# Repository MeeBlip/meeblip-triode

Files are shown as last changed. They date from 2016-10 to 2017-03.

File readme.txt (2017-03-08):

---------------------------------------------------------------------------------------------------
                     _     _ _         _        _           _      
                    | |   | (_)       | |      (_)         | |     
 _ __ ___   ___  ___| |__ | |_ _ __   | |_ _ __ _  ___   __| | ___ 
| '_ ` _ \ / _ \/ _ \ '_ \| | | '_ \  | __| '__| |/ _ \ / _` |/ _ \
| | | | | |  __/  __/ |_) | | | |_) | | |_| |  | | (_) | (_| |  __/
|_| |_| |_|\___|\___|_.__/|_|_| .__/   \__|_|  |_|\___/ \__,_|\___|
                              | |                                  
                              |_|                                                                                   
---------------------------------------------------------------------------------------------------

Change log
V1.20 2017.02.27 
- MIDI fix so that triode plays nicely with MIDI clock

V1.11 2016.11.23
- Reverted filter decay envelope to use SUSTAIN switch, as in original release 

V1.10 2016.11.12 
- Updated MIDI code to exit interrupt immediately if MIDI command is unrecognized
- Increased front panel switch scanning rate (10X faster)
- Reduced pitchbend to ± 3 semitones
- Altered filter decay envelope to ignore SUSTAIN switch so that filter sweeps continue when key is released
- Removed digital pre-filtering code (previously used on OSC A&B)
- Removed digital enveloping of OSC A & B
- Gate oscillators when amplitude envelope hits zero (prevents audio bleed through)
- Changed filter cutoff curve (use table from MeeBlip SE)
- Scale filter cutoff knob to cover 25%-100% of knob range
- Scale filter resonance knob to cover 25%-100% of knob range
- Added bandlimited square wave tables (pulse waves were previously generated with offset sawtooth ramps)
- Raw calculated waveforms are now used in the lower 4 octaves, then switch to bandlimited wavetables. 
-Flipped waveforms to match phase and avoid a pop when crossing the cut-over point
 
V1.01 2016.10.24 
- Ensure MIDI channel settings are saved correctly when powered off for Channel 1-8 (implement MAXMIDI variable)
- Allow MIDI CC control of GLIDE knob to select waves when in wavetable mode (CC 61 now controls GLIDE in wavetable mode)
- Updated MIDI code to exit interrupt immediately if MIDI command is unrecognized
- Increased front panel switch scanning rate (10X faster)

V1.00 2016.10.19 
- Initial release

---------------------------------------------------------------------------------------------------

  MeeBlip hardware is released under a Creative Commons Attribution-ShareAlike 4.0 International 
	(CC-BY-SA 4.0) license. You are free to share and transform this work, even for commercial
	purposes, providing you:

	1. Give appropriate credit, provide a link to the license, and indicate if changes were made. 
	   You can say something such as "This project is based upon the MeeBlip anode synthesizer. 
	   For more information, visit meeblip.com or download source code and design files at 
	   https://github.com/MeeBlip"

	2. If you remix, transform, or build upon the material, you must distribute your contributions
	   under the same license as the original. That means making source code, design files and PC 
	   board layout files available so someone can build and modify their own version of the project. 

	3. The MeeBlip name is our intellectual property. You are not allowed to release commercial 
	   devices based on our designs using the MeeBlip brand name. 
	
	Here's are links to the Creative Commons license, for the design:
	http://creativecommons.org/licenses/by-sa/4.0/
	http://creativecommons.org/licenses/by-sa/4.0/legalcode

	MeeBlip source code and documentation is released under a GPLv3 license. 

  A copy is available in the MeeBlip repository at:
	https://github.com/MeeBlip/meeblip-anode/blob/master/LICENSE

	MeeBlip Contributors

	Jarek Ziembicki	- Created the original AVRsynth, upon which this project is based.
	Laurie Biddulph	- Worked with Jarek to translate his comments into English, ported to Atmega16
	Daniel Kruszyna	- Extended AVRsynth (several of his ideas are incorporated in MeeBlip)
 	Julian Schmidt	- Original Meeblip digital filter algorithm
	Axel Werner		- Code optimization, bug fixes and new bandlimited waveforms 
	James Grahame 	- Meeblip hardware and firmware development

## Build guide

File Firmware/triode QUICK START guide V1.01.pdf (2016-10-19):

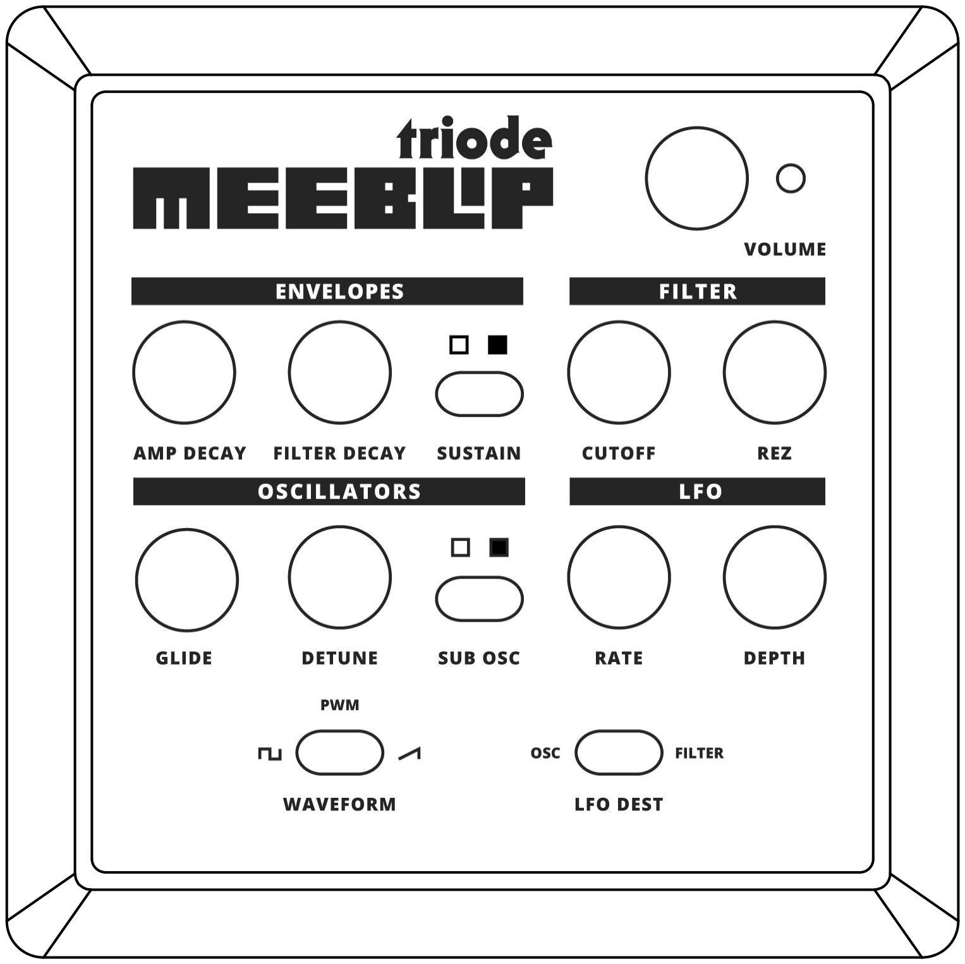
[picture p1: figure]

# QUICK START INSTRUCTIONS

### Firmware Version 1.0

Thanks for buying a MeeBlip, and welcome to triode! Let’s get started.

# Connect triode

triode requires three connections: MIDI, 9V DC power and Audio.

For audio, connect any stereo mini jack (3.5 mm) cable to an external output, or plug in stereo headphones. IMPORTANT: you must use a stereo cable connected to a stereo input jack.

MIDI input is available from any standard MIDI DIN connection. (That’s the round connector with the five pins.)

Power is 9V DC, 300 mA, 2.1mm-barrel, center positive.

# Set the MIDI Channel

Set the MIDI channel using the MIDI SET button on the back panel. Press it until the LED blinks, then release. Move one of the control knobs corresponding to channels 1 to 8. The LED will blink quickly to confirm that the MIDI channel has been changed.

# Turn it on

Flip the power switch on the back panel right to turn triode on. The power LED blinks when receiving MIDI notes.

# Adjust the controls

triode’s controls are divided into sections that control the sound of each note over time (envelope), shape its timbre (filter), control its sound source (oscillators), and add modulation (LFO).

AMPLITUDE & FILTER ENVELOPES: With SUSTAIN switched to off, triode uses single stage decay envelopes for amplitude and filter cutoff. With SUSTAIN on, they becomes two-stage envelopes (Sustain/Decay) where DECAY controls both sustain and release times. ATTACK can be adjusted for both envelopes using MIDI CC.

OSCILLATORS: triode is a three-oscillator synth. Two oscillators can be switched between Pulse, Pulse with PWM, and Sawtooth waveforms. The third is a square wave sub-oscillator which plays an octave lower.

GLIDE adjusts the speed with which notes slide from one to another. Turn the knob fully to the left to disable.

DETUNE adjusts the pitch of the second oscillator up or down an augmented fifth (eight semitones). The oscillators can be precisely tuned to each other at the 12 O’clock position of the knob.

SUB OSC activates the square wave sub-oscillator, which plays an octave lower than the primary oscillators.

LFO RATE determines the speed of the Low Frequency Oscillator (LFO). Disable by turning the knob fully to the left.

LFO DEPTH is the modulation amount of the LFO. Disable by turning knob fully to the left.

LFO DEST sets the LFO to modulate either the pitch of the two oscillators or the cutoff of the analog filter.

FILTER: triode has a unique-sounding low pass Twin-T filter, with controls for CUTOFF and REZ (resonance). Turn REZ all the way up for squelchy self-resonation. Try turning CUTOFF up and REZ down when experimenting with other values.

# Play some notes

triode responds to notes, pitch bend, mod wheel, velocity (mapped to filter cutoff), and CC messages (see table).

# How triode responds to MIDI

In addition to pitch (MIDI notes) and velocity (mapped to the filter envelope, so triode responds to how forcibly you play notes), triode responds to MIDI messages from external controllers and sequencers. MIDI numbers these messages via standard Control Change numbers, or CC:

### 01 MIDI MOD wheel (mapped to LFO Depth)

Knobs

### 48 LFO Depth 49 LFO Rate 50 Oscillator Detune 51 Note Glide (Portamento) 52 Filter Resonance 53 Filter Cutoff 54 Filter Decay 55 Amplitude Decay

Knobs only accessible via MIDI:

### 56 Filter Accent 57 Filter Envelope Modulation 58 Oscillator Pulse Width 59 Filter Attack 60 Amplitude Attack

Switches

### 64 Envelope Sustain 65 Sub-oscillator 66 PWM Sweep 67 LFO Destination (osc/filter) 68 Oscillator Wave (pulse/sawtooth)

Since switches are either in one position or another, any CC with a value from 0-63 will correspond to “off”; any value from 64-127 will result in “on.”

Switches only accessible via MIDI:

### 69 LFO Randomize 70 LFO Note Retrigger (default ON)

# To activate Wavetable Mode

Hold the MIDI Set button for a moment while turning the instrument on. The LED will flash quickly to indicate that it has switched firmware. The WAVEFORM switch selects Wavetable Bank A / B / C and the GLIDE knob selects one of the 8 waveforms in each bank.

Wave Bank A: Sawtooth, Blended Sawtooth, FM 1, Distorted 1, Granular 1, Voice 1, Voice 2

Wave Bank B: Bit Reduced 1, Bit Reduced 2, Bit Reduced 3, Distorted 2, Distorted 3, FM 2, FM 3, More Granular.

Wave Bank C: Chip Osc 1, Chip Osc 2, Video Game 1, Video Game 2, Bit Reduced 4, Bit Reduced 5, Raw 1, Raw 2

# What’s next?

Have fun! You can find advanced documentation including schematic diagrams and source code, at our site: meeblip.com. You can also email us at meeblip@reflexaudio.com

Assembled in Canada by Blipsonic Inc. MeeBlip is a project of Blipsonic and CDM (cdm.link)

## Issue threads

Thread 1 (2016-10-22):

The Triode should better filter unknown MIDI messages

samboy, 2016-10-22:
There is an issue reported by [a user on Reddit](https://www.reddit.com/r/synthesizers/comments/58phrq/filtering_out_midi_clock/) that the Meeblip Triode has issues receiving MIDI note on messages when receiving a number of presumably unknown MIDI messages, probably either MIDI [Song Position Pointer](http://www.recordingblogs.com/sa/Wiki/topic/MIDI-Song-Position-Pointer-message) or [MTC](https://en.wikipedia.org/wiki/MIDI_timecode) message.

Looking at [mini_in.inc](https://github.com/MeeBlip/meeblip-triode/blob/master/Firmware/midi_in.inc), as of commit c66a3ed, there is code between lines 23 and 29 which immediately removes the Triode from the interrupt caused by a MIDI message sent should it be a byte between F0 and FF. And, indeed, when my Triode gets a [MIDI Beat Clock](https://en.wikipedia.org/wiki/MIDI_beat_clock) message from my Korg ER-1 along with note-on commands, the Triode is able to play the notes without problem, since MIDI Beat Clock only consists of the bytes F8, FA, FB, and FC.

However, the Triode stops being able to respond to MIDI messages when getting more complicated unknown MIDI messages. Looking at mini_in.inc, the issue appears to be that, when MIDIPHASE (the byte of a MIDI message we are looking at) is 0, and an unknown byte is received, instead of immediately exiting from the MIDI interrupt, mini_in.inc compares the incoming byte and MIDIPHASE to a number of possible values before finally exiting the interrupt.

To resolve this, I propose adding two instructions right after the INTRX_DATA jump point, on line 73 of the current version of midi_in.inc, like this:

```
INTRX_DATA:
 lds r17, MIDIPHASE ; This is already here on line 73
 cpi r17, 0 ; On the old 6502, this isn't needed
 breq INTRX_ACPT_X ; Which will jump us to INTRX_EXIT
 cpi r17, 0x80 ; This is in the current code; go on as the current code does
```

Thoughts? This fix should make the Triode more useful when slaved to devices which send complex MIDI data when sending out a clock signal over MIDI.

Edit: Looking at the code again, INTRX_ACPT_X is close enough to this that we can call that with [BREQ](http://www.atmel.com/webdoc/avrassembler/avrassembler.wb_BREQ.html)

jgrahame, 2016-10-23:
Will implement and test.

jgrahame, 2016-10-25:
Hi Sam -

Thanks for the message. Will have to do a careful walkthrough to be sure,
but this might sort the issue out. Will try it later this weekend and let
you know how things go.

Cheers, James

On Fri, Oct 21, 2016 at 10:46 PM, Sam Trenholme <notifications@github.com>
wrote:

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

jgrahame, 2016-10-26:
Implemented change. Tested extensively and couldn't get it to fail. Online comments suggest Elektron is doing something unusual with the Octatrack MIDI clock output. Will investigate with their hardware.

jgrahame, 2016-10-29:
Hey sam -

After feedback from users...

We'll be releasing V1.1 of the firmware next week, which has MIDI
improvements, better filter behaviour (especially low), better
enveloping and some voicing improvements as well. It's a significant
upgrade that makes a big difference to the instrument's sound.

The upgrade will be available as a replacement chip or download for
people who own AVR programmers. More details soon!

James Grahame

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

samboy, 2016-11-01:
How much will a replacement ATmega chip for the Triode cost, and how can one go about ordering one?

— Sam (I prefer the chip solution, because, over the long term, it’s more sustainable)

Closed 2016-10-26.

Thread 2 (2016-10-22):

Midi channels above 4 are not restored

oO, 2016-10-22:
When I set the midi channel to 8, the triode reverts to channel 0 / omni mode on power up.

The initialize code checks for midi channel < 5 but we can now pick values from 1-8 as valid midi channels?

initialize.inc line 223
````asm
cpi		r16, 5
brlo	LOAD_MIDI_CHANNEL		; If stored MIDI Channel is not Channel 1-4, set synth into MIDI OMNI mode.
ldi		r16, 0
````

Seems that you should check for values less than 16 instead, and worry about how many channel the synth supports somewhere else.

In the future, you could check for a change in the state of a switch to toggle between midi 1-8 and 9-16 and support setting the synth to any channel. and not just the lower 8 channels.

jgrahame, 2016-10-23:
This should be an easy fix. Will implement in the next release.

jgrahame, 2016-10-26:
Added MAXMIDI variable. Synth now restores channel 1-8 after being powered down.

oO-Zam, 2016-10-31:
@jgrahame what's the process to update the firmware? I'm assuming the .hex file is updated to 1.01, so I can just fire up AVRDUDE and flash it? ( don't think you have the onboard programming pins exposed on the synth, right? )

Closed 2016-10-26.

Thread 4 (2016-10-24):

Midi CC for Sub-Oscillator level (volume)

oO, 2016-10-24:
Looking at the code, (not an Assembly programmer, so it reads, very very slowly) it seems possible to support control of the sub-oscillator level from Midi CC (I guess a mult rather than a if somewhere?) . I would change the way the CC#64 works by using the full range 0-127 for volume, instead of on/off at >=64. You can still have full bypass of the sub calculation at level = 0

Also is the sub-oscillator 1 or 2 octaves down? This is orthogonal from the Midi CC question, but since your switches have 2 states, you could actually have the sub function as Off/-1/-2

jgrahame, 2016-10-26:
The sub-osc output is mixed with the main oscillators as an analog signal. There is no control of amplitude.

Closed 2016-10-26.

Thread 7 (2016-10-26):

Publish a BOM

oO, 2016-10-26:
Since the MeeBlip is Open Hardware / Open Source, would you mind adding a Bill Of Materials to the repository? Also I'm guessing you don't have a bootstrap and program the ATMEGA chip directly?

I might play with an alternate build at some point, but I'll probably do it on a separate chip, and keep yours for the "official" build.

Great little bass synth BTW, it sounds really dirty but that's not a bad thing.

lukeoftheaura, 2017-06-04:
+1 for adding a BOM.

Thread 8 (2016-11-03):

panic button for hung notes

oO-Zam, 2016-11-03:
I'm getting a lot of stuck notes and missed midi events from my MeeBlip when driving it from the Squarp Pyramid. It would be great to have the midi button stop all open notes when pressed ( or whatever scheme would allow me to have a quick "panic button" to use.

Alternativelly, supporting the "AllNotesOff" midi message would also be great.

jgrahame, 2016-11-03:
We'll be releasing a firmware update later this week that uses significantly fewer processor cycles, would be great if you could test that with the Pyramid.

oO-Zam, 2016-11-03:
Will do. Still think turning the button into a panic button would be great. You can double up with the Midi setting, since you probably want to stop all notes when switching channels.

jgrahame, 2017-04-12:
Version 1.20 fixes issues with MIDI clock and hung notes.

Closed 2017-04-12.

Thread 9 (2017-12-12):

3-way switch via midi isn't working

evanmcc, 2017-12-12:
Hi, I have a triode and have only recently been playing with wavetable mode.  I've also gotten a new sequencer recently and in programming in the various CCs for the meeblip, I noticed that the three-way switch only does positions one and three via MIDI, right at value 64, as you'd expect from a two-way switch.  The hardware works fine.  I think that I confirmed that you can't get PWM via MIDI either.

Also a feature request, albeit one that might not be possible: I'd love to be able to trigger wavetable mode via CC as well, as it'd go a long way towards being able to replicate patch memory in the sequencer.

Lastly a hardware question: is modding the triode to be actually mono as simple as snipping the ring legs on the socket, or will that not work?

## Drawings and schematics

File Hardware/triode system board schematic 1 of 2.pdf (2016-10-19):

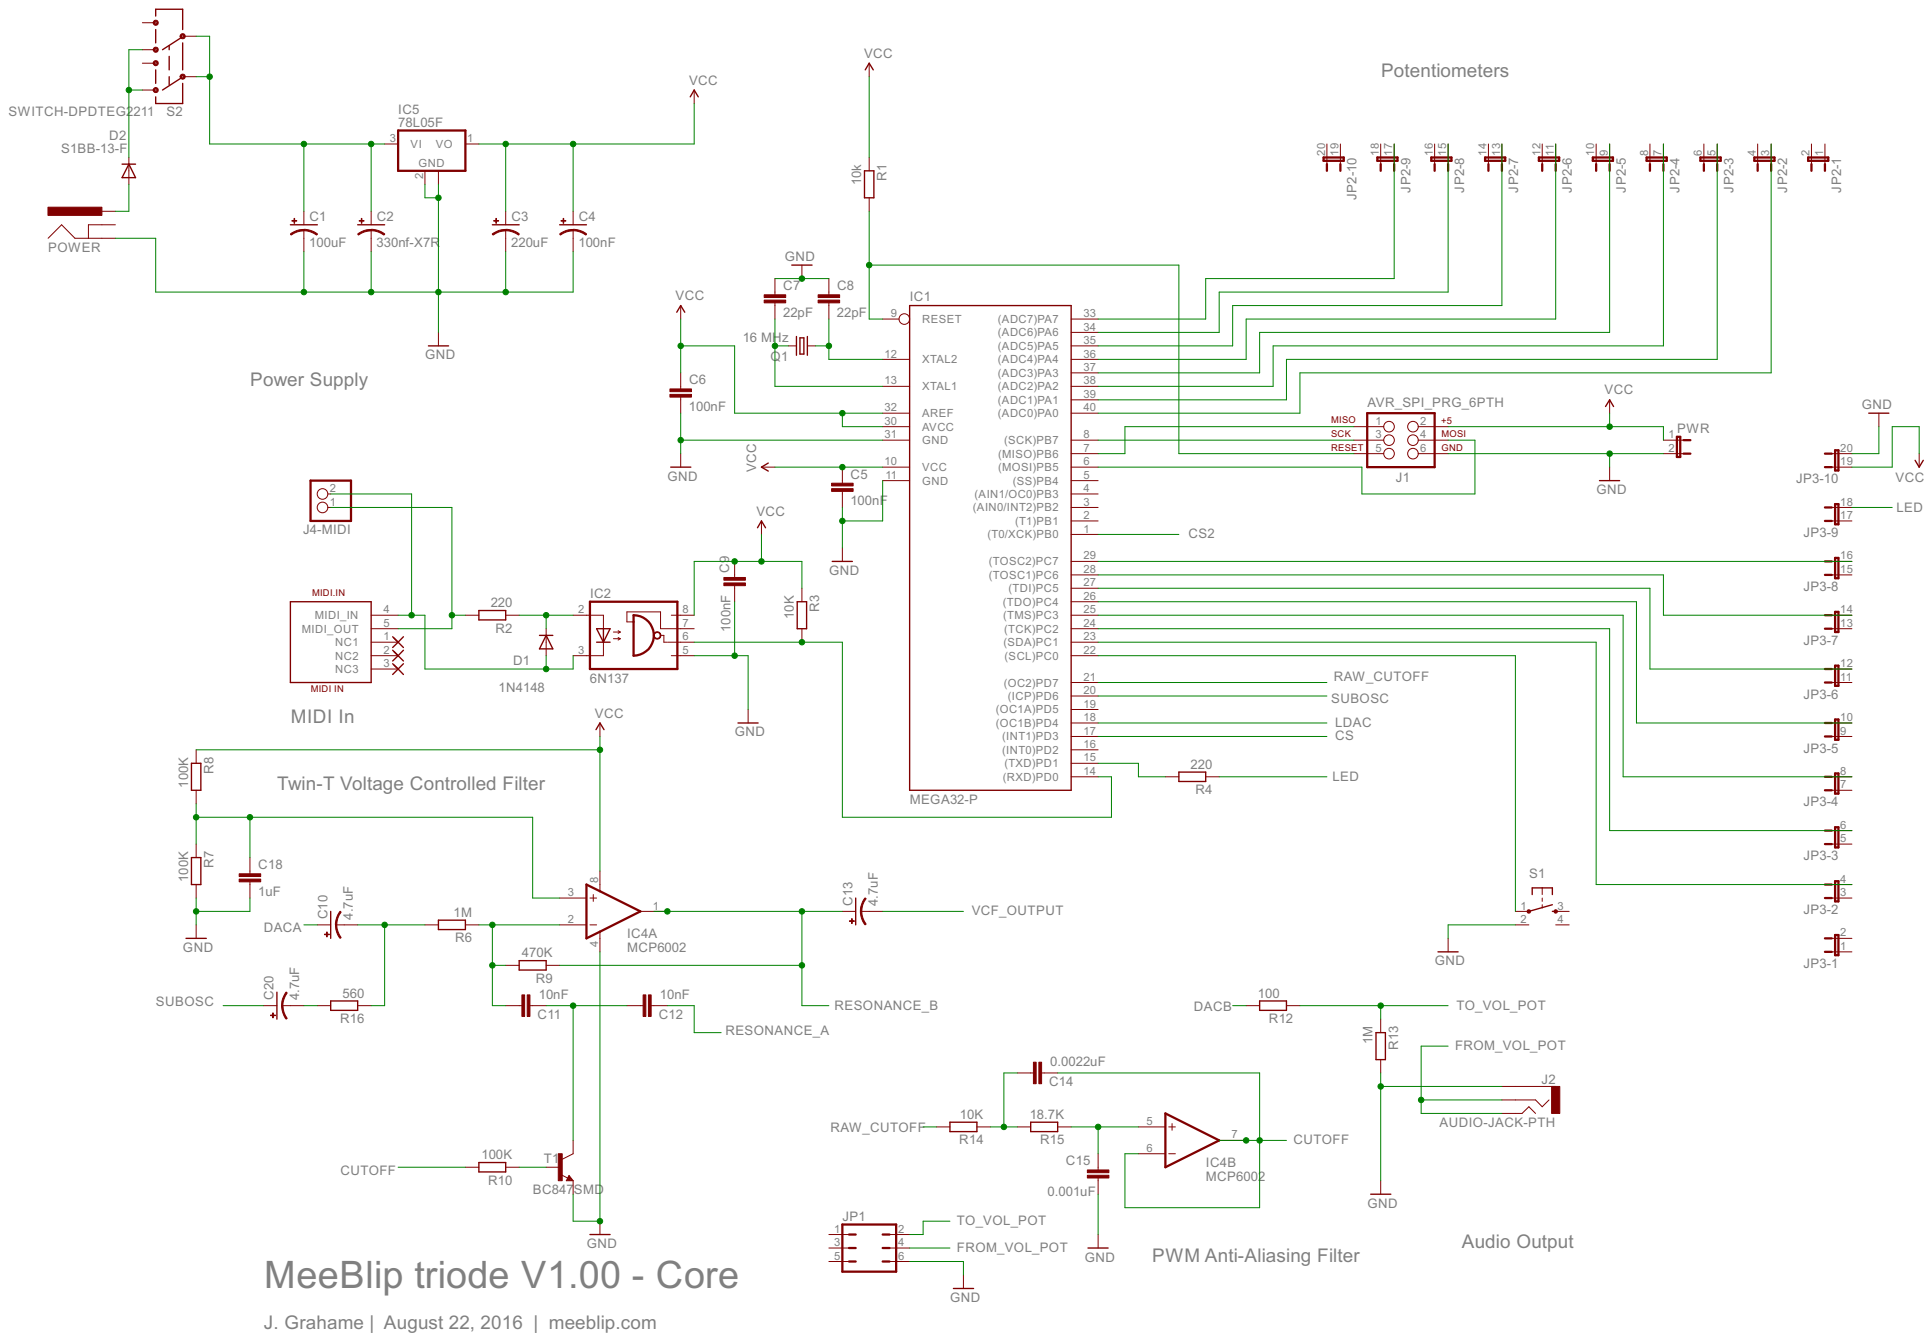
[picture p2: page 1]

MIDI.IN MIDI IN

Twin-T Voltage Controlled Filter

J. Grahame | August 22, 2016 | meeblip.com

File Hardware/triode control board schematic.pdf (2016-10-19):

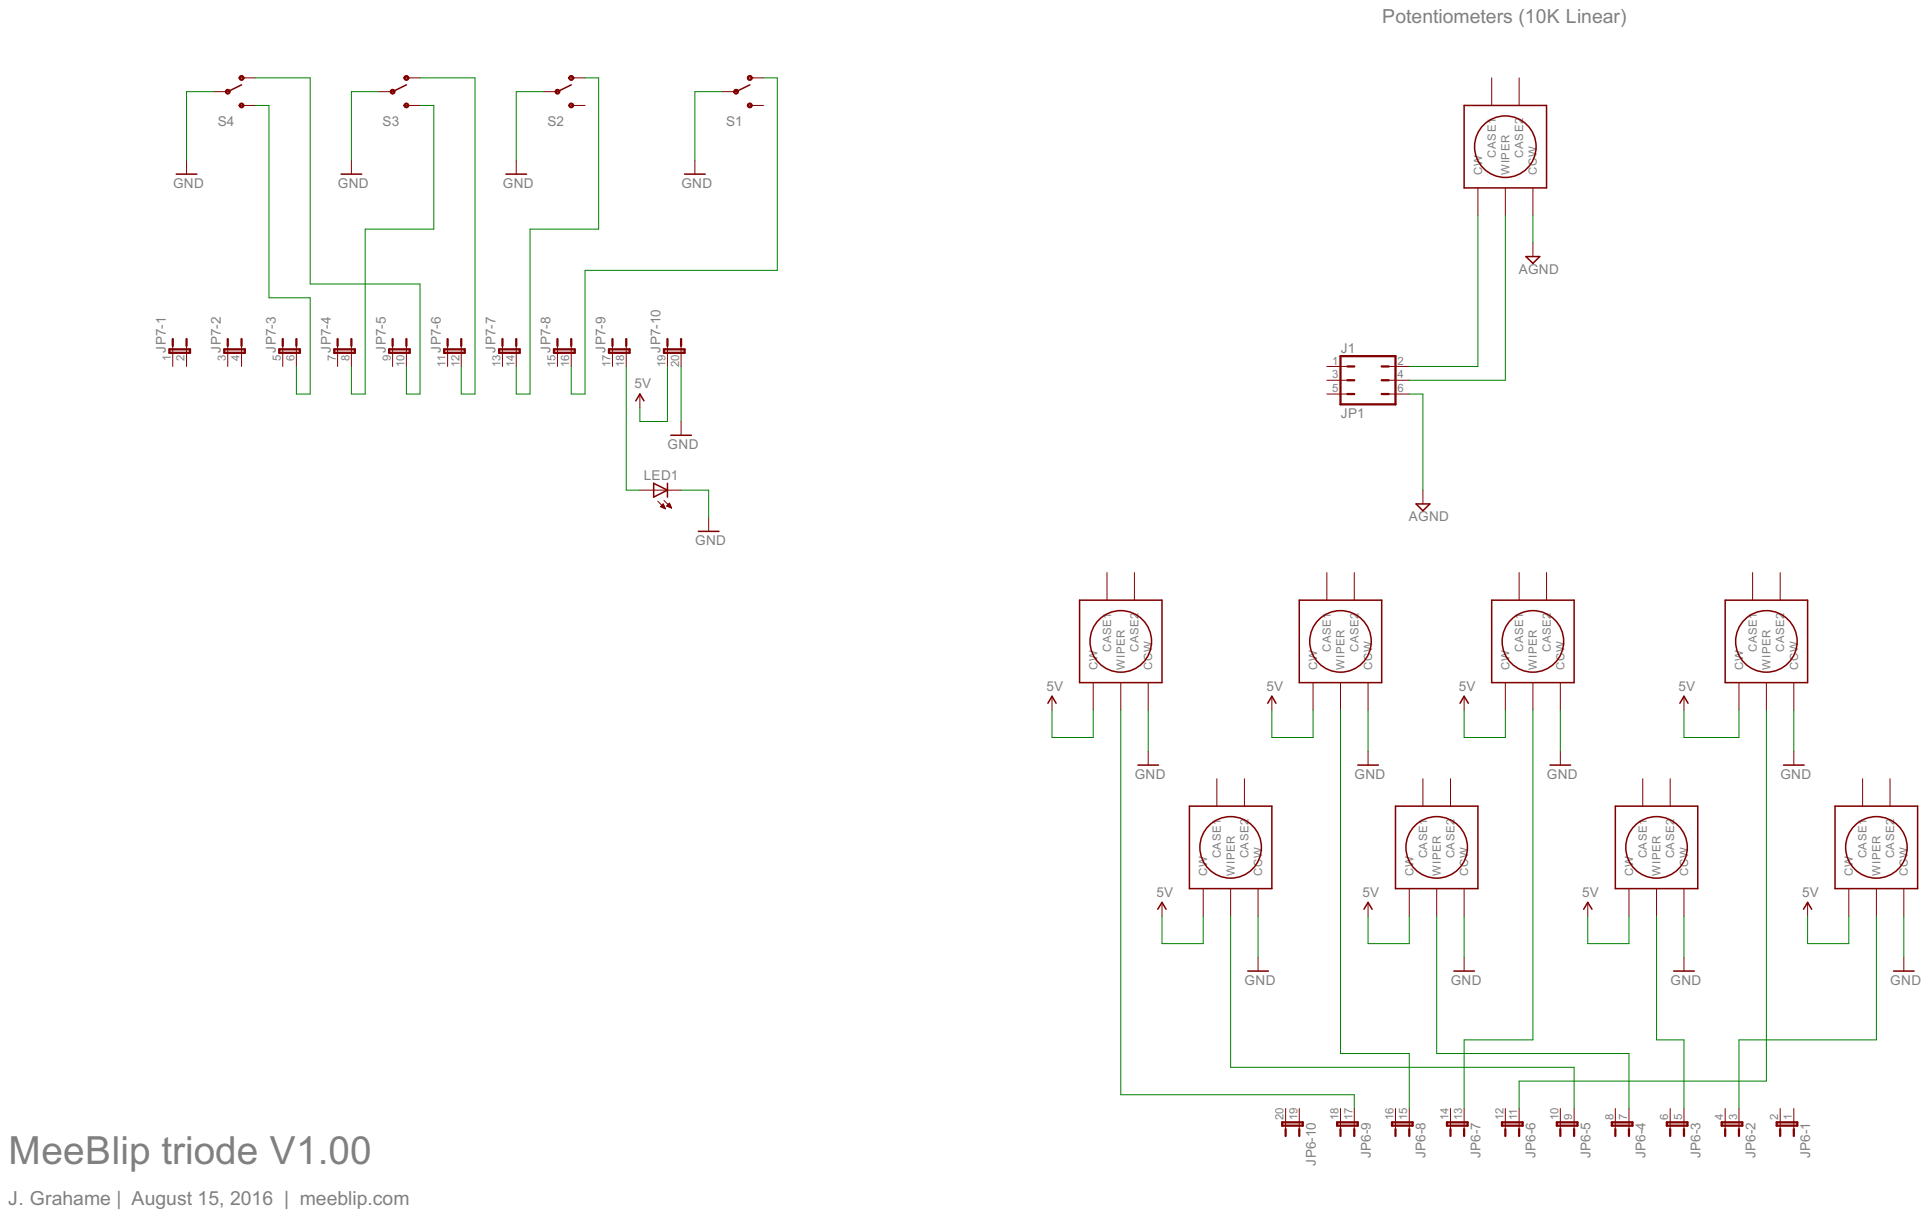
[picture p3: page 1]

J. Grahame | August 15, 2016 | meeblip.com

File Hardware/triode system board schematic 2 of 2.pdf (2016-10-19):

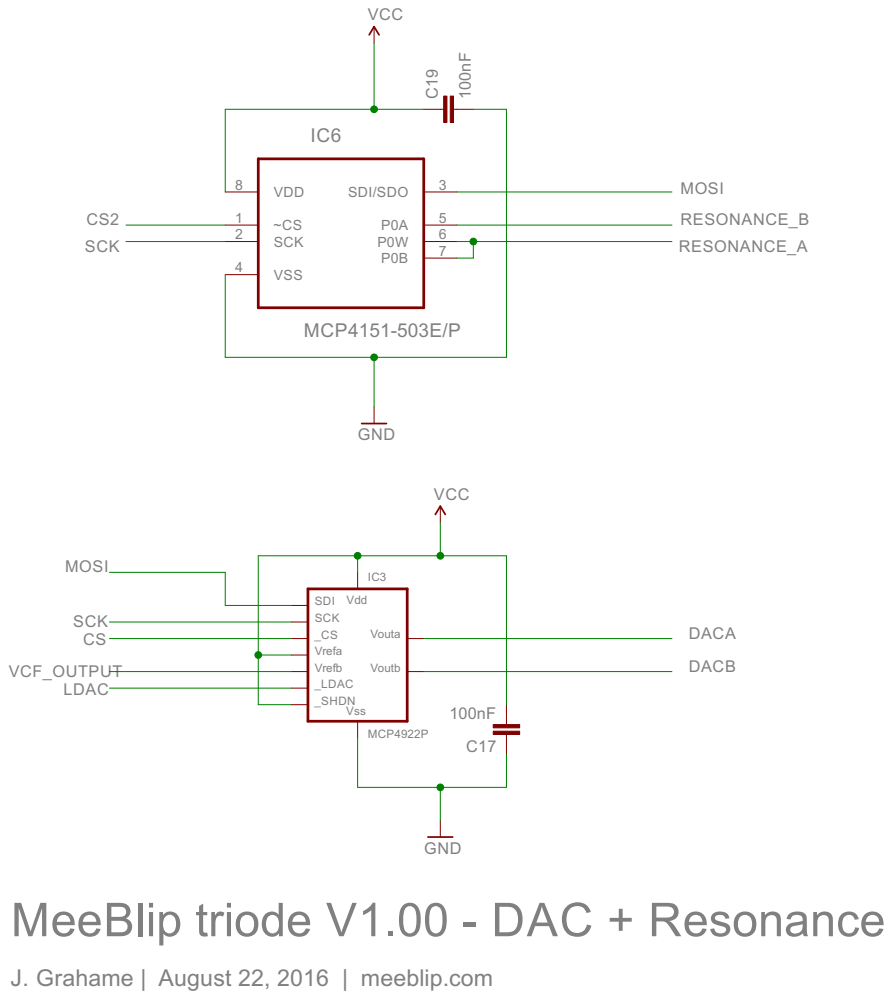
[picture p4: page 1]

MeeBlip triode V1.00 - DAC + Resonance

J. Grahame | August 22, 2016 | meeblip.com

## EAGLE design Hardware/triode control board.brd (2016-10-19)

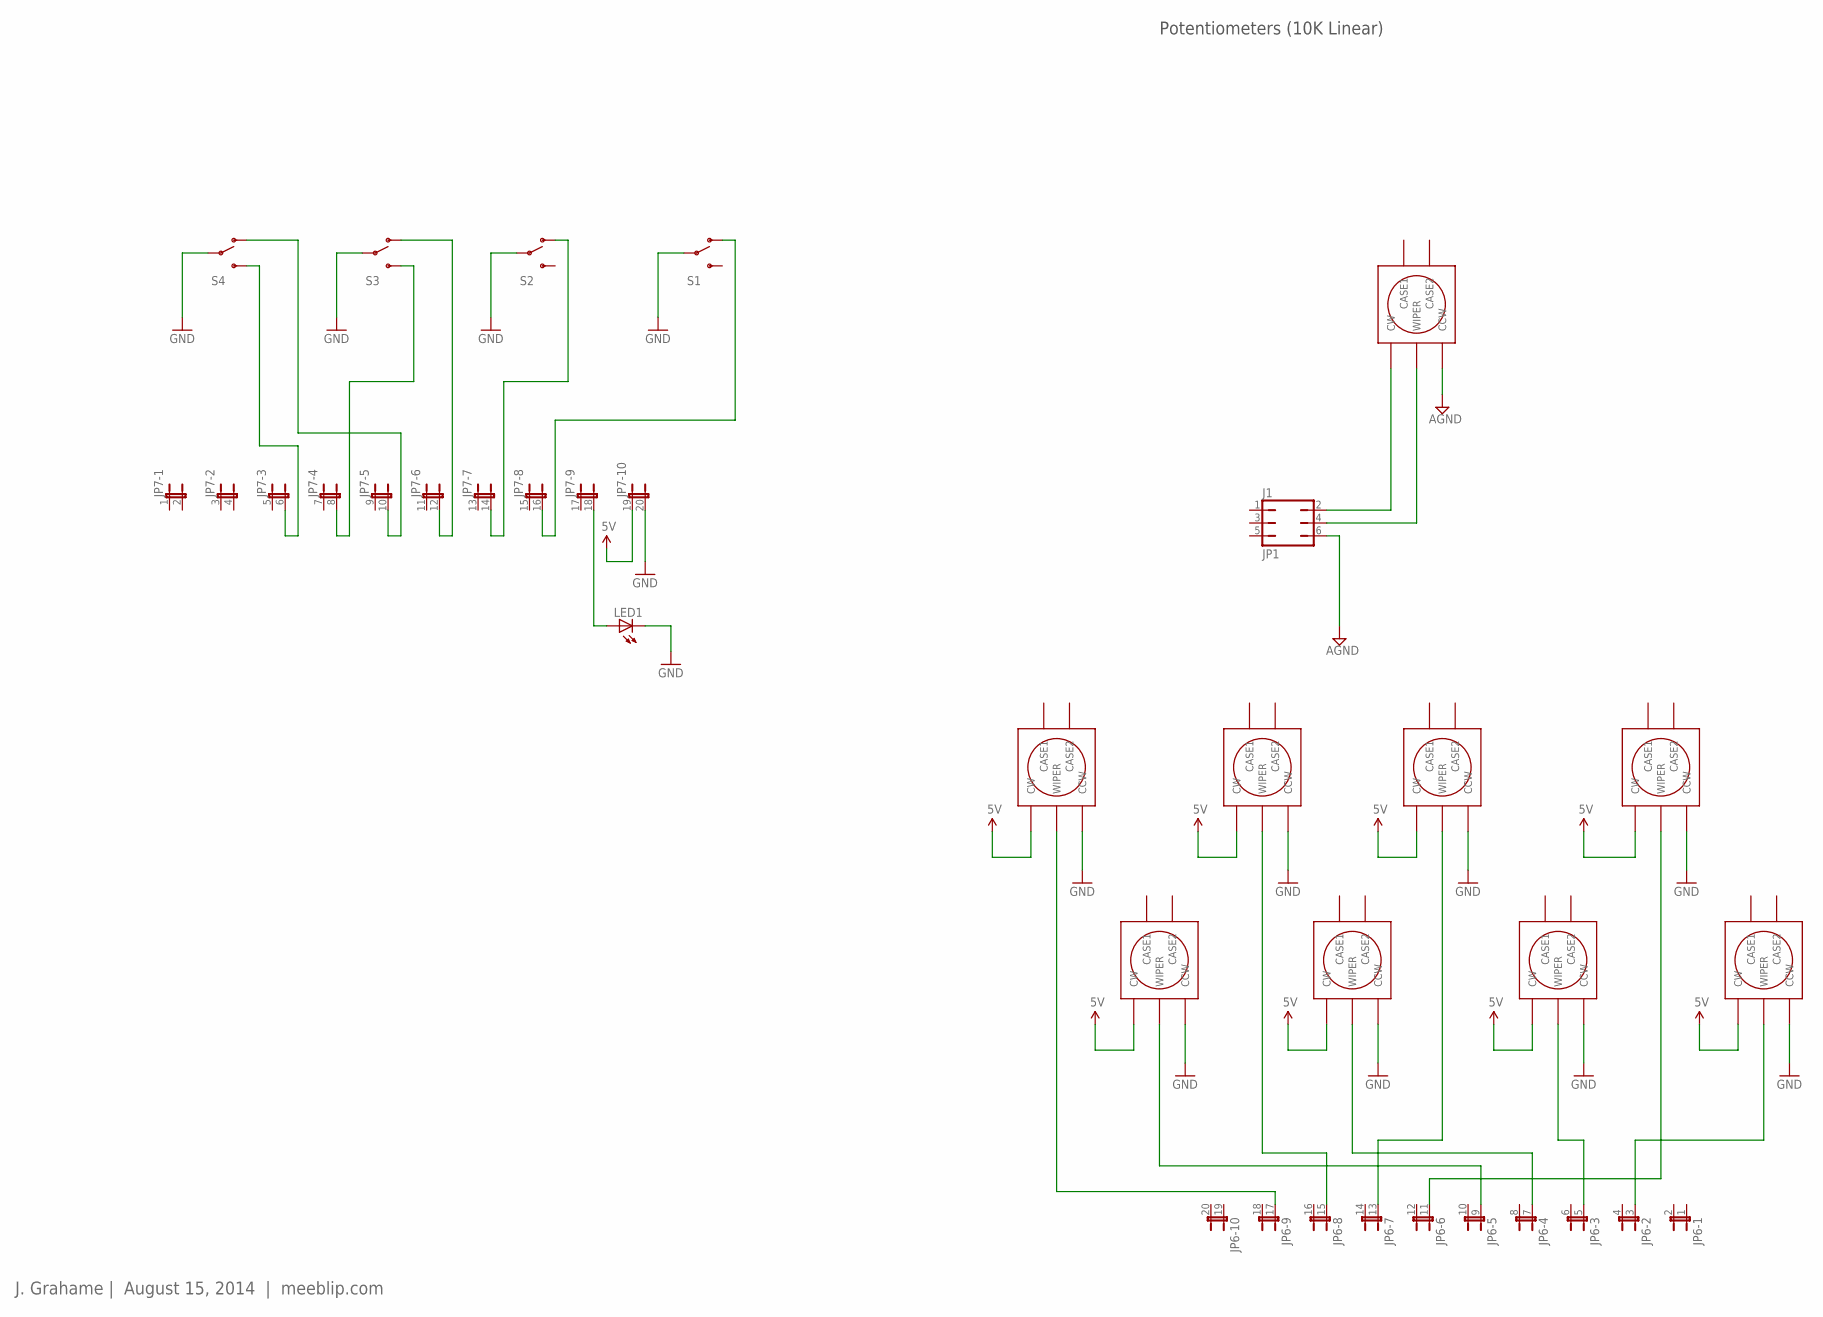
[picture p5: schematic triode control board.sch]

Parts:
J1: JP1; JP3Q
JP6, JP7: JP10QE; JP10Q
LED1: LED3MM
POT1, POT2, POT3, POT4, POT5, POT6, POT7, POT8, POT9: VACOLOCO_EVUFRK09_POT; VACOLOCO_EVUF
S1, S2, S3, S4: SWITCH-SPSTMHS122K; SWITCH-SPDT

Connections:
5V: JP7.19 (1), POT2.CW, POT3.CW, POT4.CW, POT5.CW, POT6.CW, POT7.CW, POT8.CW, POT9.CW
AGND: J1.6, POT1.CCW
GND: JP7.20 (2), LED1.K (C), POT2.CCW, POT3.CCW, POT4.CCW, POT5.CCW, POT6.CCW, POT7.CCW, POT8.CCW, POT9.CCW, S1.2, S2.2, S3.2, S4.2
unnamed: J1.2, POT1.CW
unnamed: JP7.18 (2), LED1.A
unnamed: JP6.17 (1), POT2.WIPER
unnamed: JP6.15 (1), POT3.WIPER
unnamed: JP7.16 (2), S1.1 (O)
unnamed: JP7.14 (2), S2.1 (O)
unnamed: JP6.13 (1), POT4.WIPER
unnamed: JP6.9 (1), POT6.WIPER
unnamed: JP6.7 (1), POT7.WIPER
unnamed: JP7.12 (2), S3.1 (O)
unnamed: JP7.10 (2), S4.1 (O)
unnamed: JP6.5 (1), POT8.WIPER
unnamed: JP6.3 (1), POT9.WIPER
unnamed: J1.4, POT1.WIPER
unnamed: JP6.11 (1), POT5.WIPER
unnamed: JP7.6 (2), S4.3 (S)
unnamed: JP7.8 (2), S3.3 (S)

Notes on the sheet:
Potentiometers (10K Linear)
J. Grahame | August 15, 2014 | meeblip.com

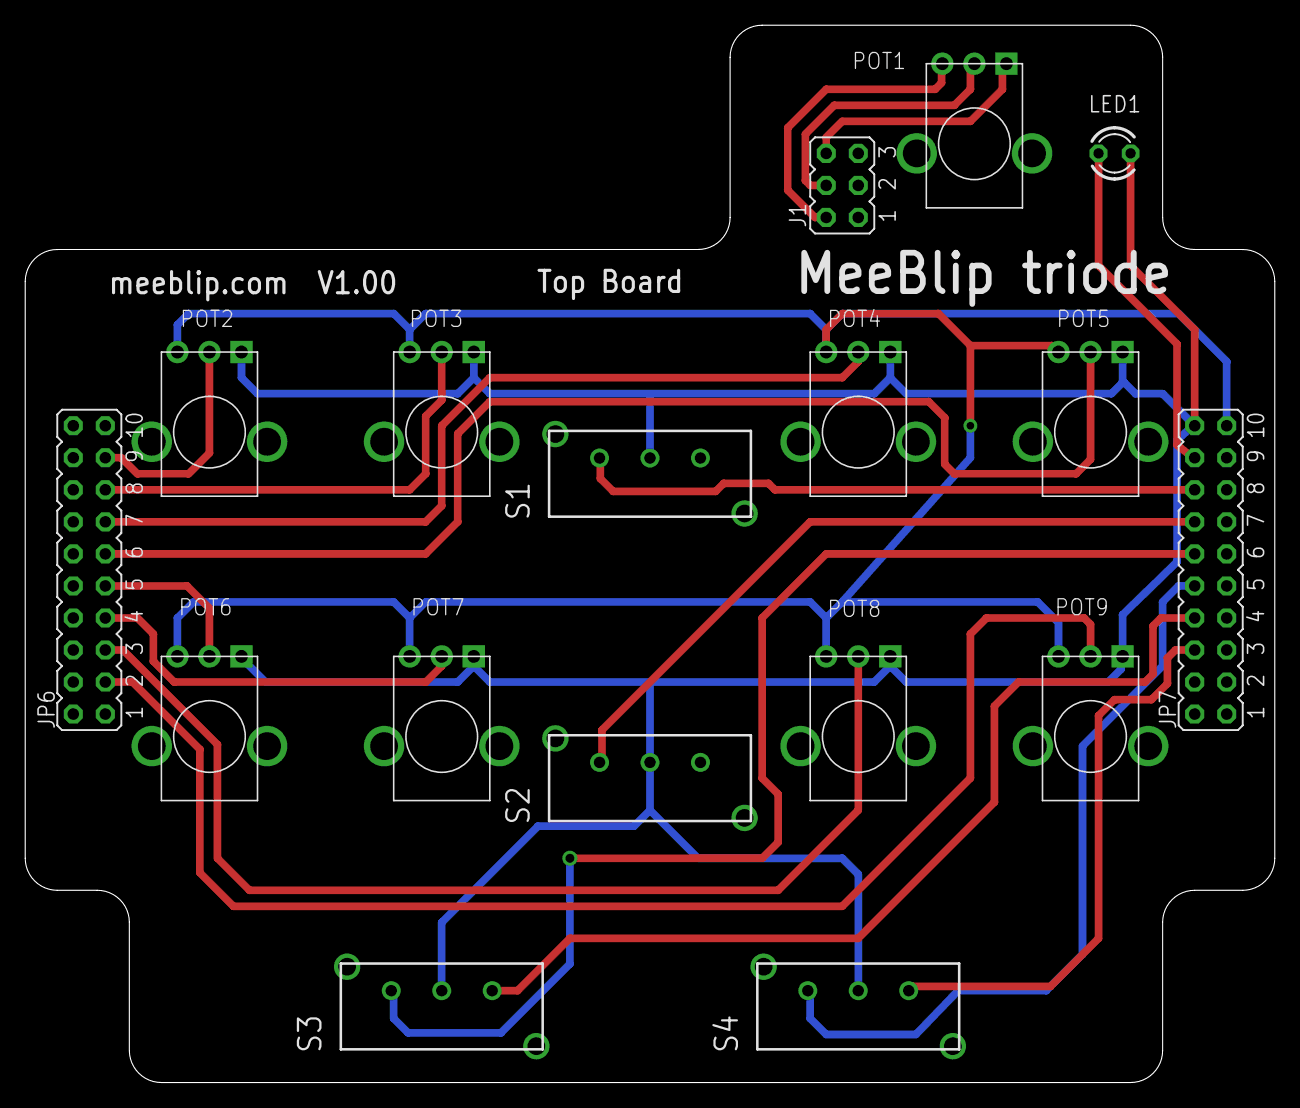
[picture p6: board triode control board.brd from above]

Board: 2 copper layers, 99.1 x 83.8 mm, 17 parts (0 on the bottom side), 20 nets.

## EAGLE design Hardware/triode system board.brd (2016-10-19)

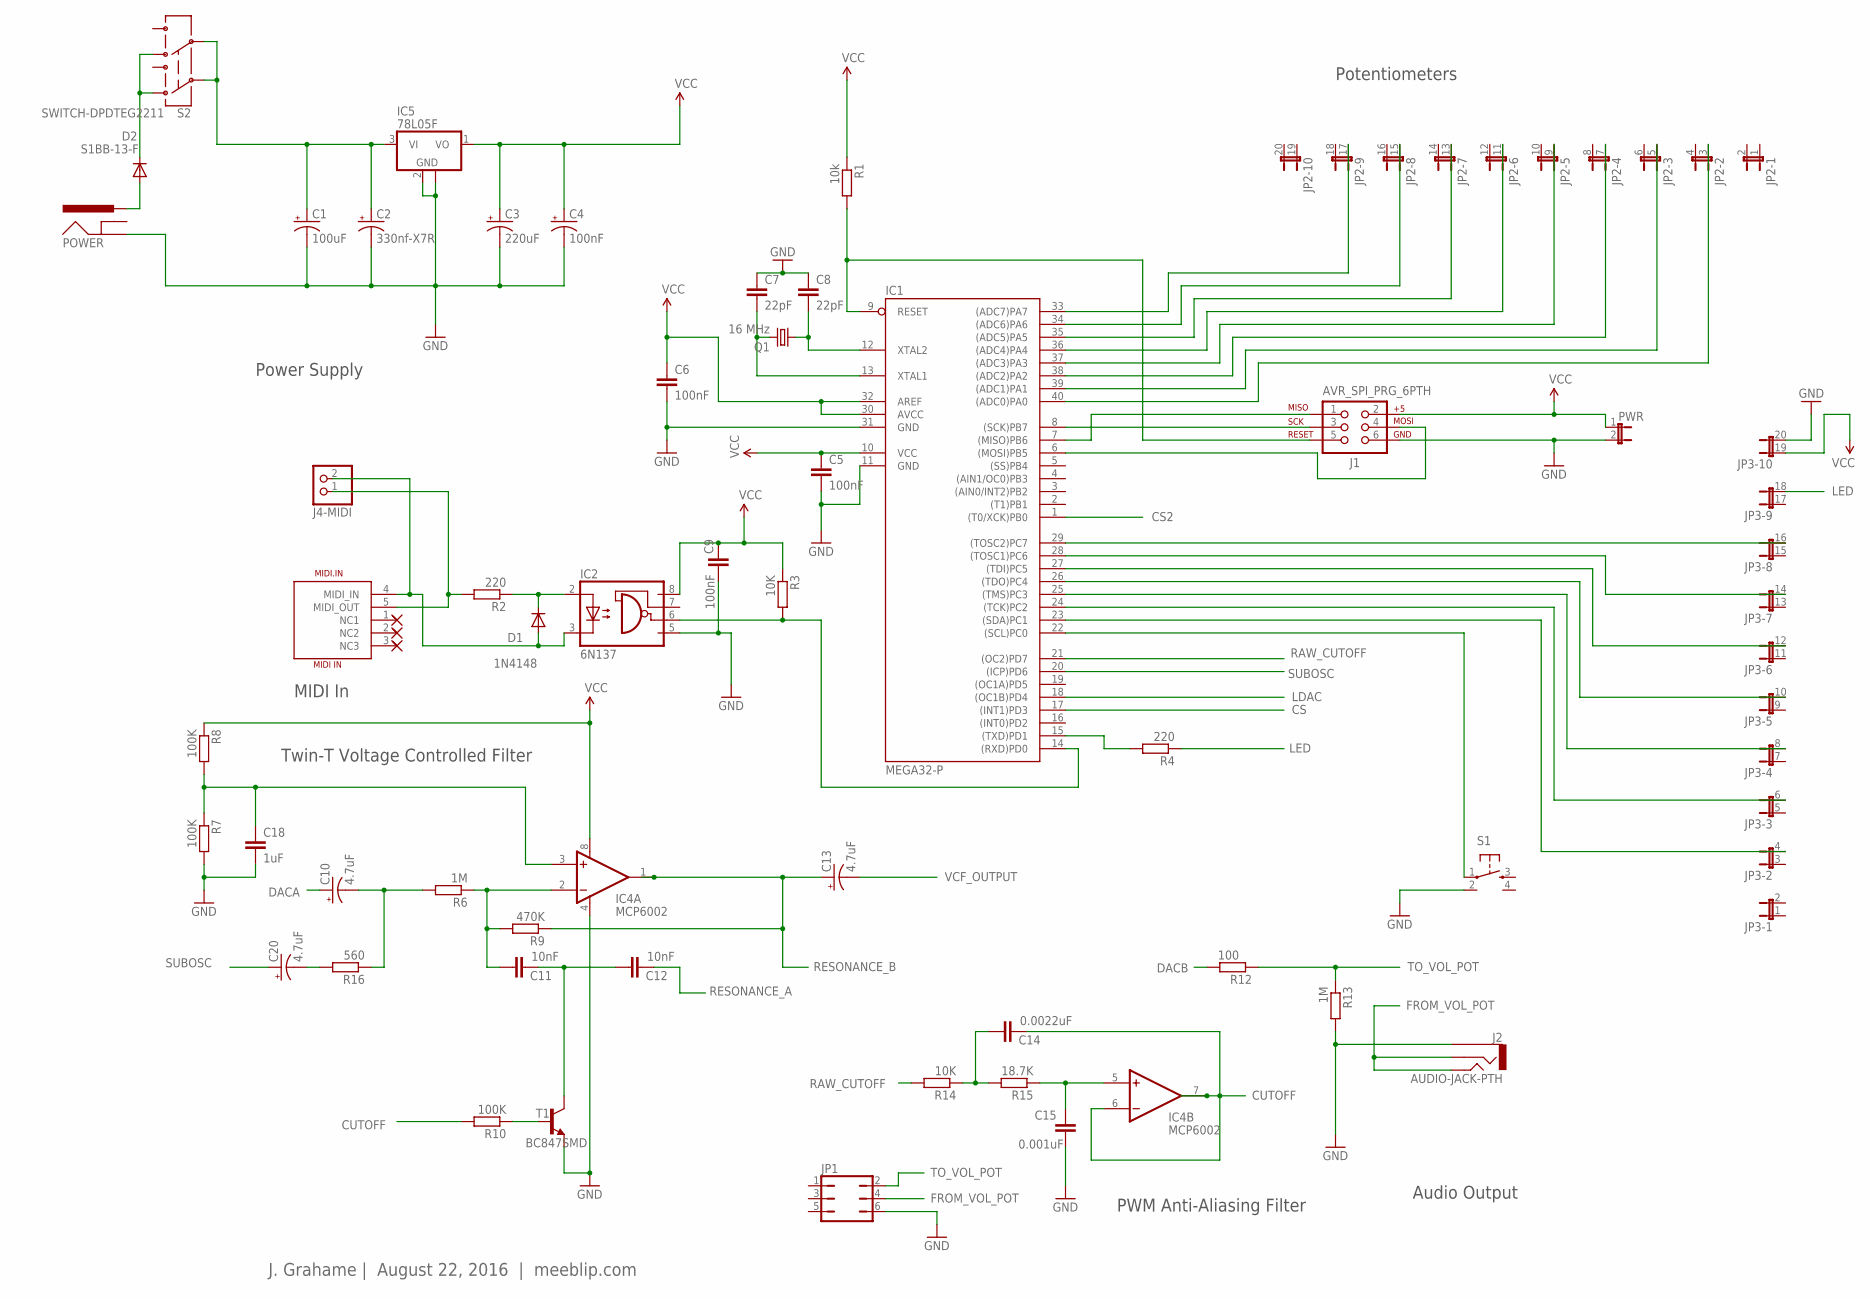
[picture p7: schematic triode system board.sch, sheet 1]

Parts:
C1: 100uF; PANASONIC_D
C2: 330nf-X7R; PANASONIC_C
C3: 220uF; PANASONIC_D
C4: 100nF; PANASONIC_C
C5, C6, C9: 100nF; 0603-CAP
C7, C8: 22pF; 0603-CAP
C10, C13, C20: 4.7uF; PANASONIC_C
C11, C12: 10nF; 0603-CAP
C14: 0.0022uF; 0603-CAP
C15: 0.001uF; 0603-CAP
C18: 1uF; 0603-CAP
D1: 1N4148; SOD123
D2: S1BB-13-F; SMA-DO214AC
IC1: MEGA32-P; DIL40
IC2: 6N137; DIL08
IC4: MCP6002; DIL08
IC5: 78L05F; SOT89
J1: AVR_SPI_PRG_6PTH; 2X3
J2: AUDIO-JACK-PTH; AUDIO-JACK
J4-MIDI: PINHD-1X2; 1X02
JP1: JP3Q
JP2, JP3: JP10QE; JP10Q
MIDI.IN: MIDI IN; DIN_5_FEMALE_SUPPORT
POWER: POWER_JACKPTH; POWER_JACK_PTH
PWR: JUMPER-2PTH; 1X02
Q1: 16 MHz; HC49UP
R1: 10k; M1206
R2, R4: 220; M1206
R3, R14: 10K; M1206
R6, R13: 1M; M1206
R7, R8, R10: 100K; M1206
R9: 470K; M1206
R12: 100; M1206
R15: 18.7K; M1206
R16: 560; M1206
S1: TAC_SWITCHPTH; TACTILE-PTH
S2: SWITCH-DPDTEG2211; EG2208A
T1: BC847SMD; SOT23

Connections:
CS: IC1.17 ((INT1)PD3); also elsewhere on the board
CS2: IC1.1 ((T0/XCK)PB0); also elsewhere on the board
CUTOFF: C14.2, IC4.6 (-IN), IC4.7 (OUT), R10.2
DACA: C10.+; also elsewhere on the board
DACB: R12.2; also elsewhere on the board
FROM_VOL_POT: J2.2, J2.5, JP1.4
GND: C1.-, C2.-, C3.-, C4.-, C5.2, C6.2, C7.1, C8.1, C9.2, C15.2, C18.2, IC1.11 (GND), IC1.31 (GND), IC2.5 (GND), IC4.4 (V-), IC5.2 (GND), IC5.2@1 (GND), J1.6, J2.1, JP1.6, JP3.20 (2), POWER.GND, PWR.2, R7.2, R13.2, S1.2, T1.2 (E); also elsewhere on the board
LDAC: IC1.18 ((OC1B)PD4); also elsewhere on the board
LED: JP3.18 (2), R4.1
MIDI-RX: J4-MIDI.1, MIDI.IN.5 (MIDI_OUT), R2.2
MOSI: IC1.6 ((MOSI)PB5), J1.4; also elsewhere on the board
unnamed: C8.2, IC1.12 (XTAL2), Q1.1
unnamed: C7.2, IC1.13 (XTAL1), Q1.2
unnamed: IC1.40 ((ADC0)PA0), JP2.3 (1)
unnamed: D2.K (C), S2.P1-TA (1), S2.P2-TA (4)
unnamed: IC1.7 ((MISO)PB6), J1.1
unnamed: IC1.9 (RESET), J1.5, R1.2
unnamed: IC1.23 ((SDA)PC1), JP3.4 (2)
unnamed: IC1.24 ((TCK)PC2), JP3.6 (2)
unnamed: IC1.25 ((TMS)PC3), JP3.8 (2)
unnamed: IC1.26 ((TDO)PC4), JP3.10 (2)
unnamed: IC1.27 ((TDI)PC5), JP3.12 (2)
unnamed: IC1.28 ((TOSC1)PC6), JP3.14 (2)
unnamed: IC1.15 ((TXD)PD1), R4.2
unnamed: IC1.29 ((TOSC2)PC7), JP3.16 (2)
unnamed: IC1.39 ((ADC1)PA1), JP2.5 (1)
unnamed: IC1.22 ((SCL)PC0), S1.1
unnamed: IC1.38 ((ADC2)PA2), JP2.7 (1)
unnamed: IC1.37 ((ADC3)PA3), JP2.9 (1)
unnamed: IC1.36 ((ADC4)PA4), JP2.11 (1)
unnamed: IC1.35 ((ADC5)PA5), JP2.13 (1)
unnamed: C11.1, IC4.2 (-IN), R6.1, R9.2
unnamed: IC1.34 ((ADC6)PA6), JP2.15 (1)
unnamed: IC1.33 ((ADC7)PA7), JP2.17 (1)
unnamed: IC1.14 ((RXD)PD0), IC2.6 (VO), R3.2
unnamed: D2.A, POWER.PWR
unnamed: C1.+, C2.+, IC5.3 (VI), S2.P1 (2), S2.P2 (5)
unnamed: C20.-, R16.2
unnamed: C18.1, IC4.3 (+IN), R7.1, R8.2
unnamed: C10.-, R6.2, R16.1
unnamed: C11.2, C12.1, T1.3 (C)
unnamed: R10.1, T1.1 (B)
unnamed: D1.C, IC2.2 (A), R2.1
unnamed: D1.A, IC2.3 (C), J4-MIDI.2, MIDI.IN.4 (MIDI_IN)
unnamed: C14.1, R14.1, R15.2
unnamed: C15.1, IC4.5 (+IN), R15.1
RAW_CUTOFF: IC1.21 ((OC2)PD7), R14.2
RESONANCE_A: C12.2; also elsewhere on the board
RESONANCE_B: C13.+, IC4.1 (OUT), R9.1; also elsewhere on the board
SCK: IC1.8 ((SCK)PB7), J1.3; also elsewhere on the board
SUBOSC: C20.+, IC1.20 ((ICP)PD6)
TO_VOL_POT: JP1.2, R12.1, R13.1
VCC: C3.+, C4.+, C5.1, C6.1, C9.1, IC1.10 (VCC), IC1.30 (AVCC), IC1.32 (AREF), IC2.8 (VCC), IC4.8 (V+), IC5.1 (VO), J1.2, JP3.19 (1), PWR.1, R1.1, R3.1, R8.1; also elsewhere on the board
VCF_OUTPUT: C13.-; also elsewhere on the board

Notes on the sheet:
PWM Anti-Aliasing Filter
Audio Output
MIDI In
Power Supply
Potentiometers
J. Grahame | August 22, 2016 | meeblip.com
Twin-T Voltage Controlled Filter

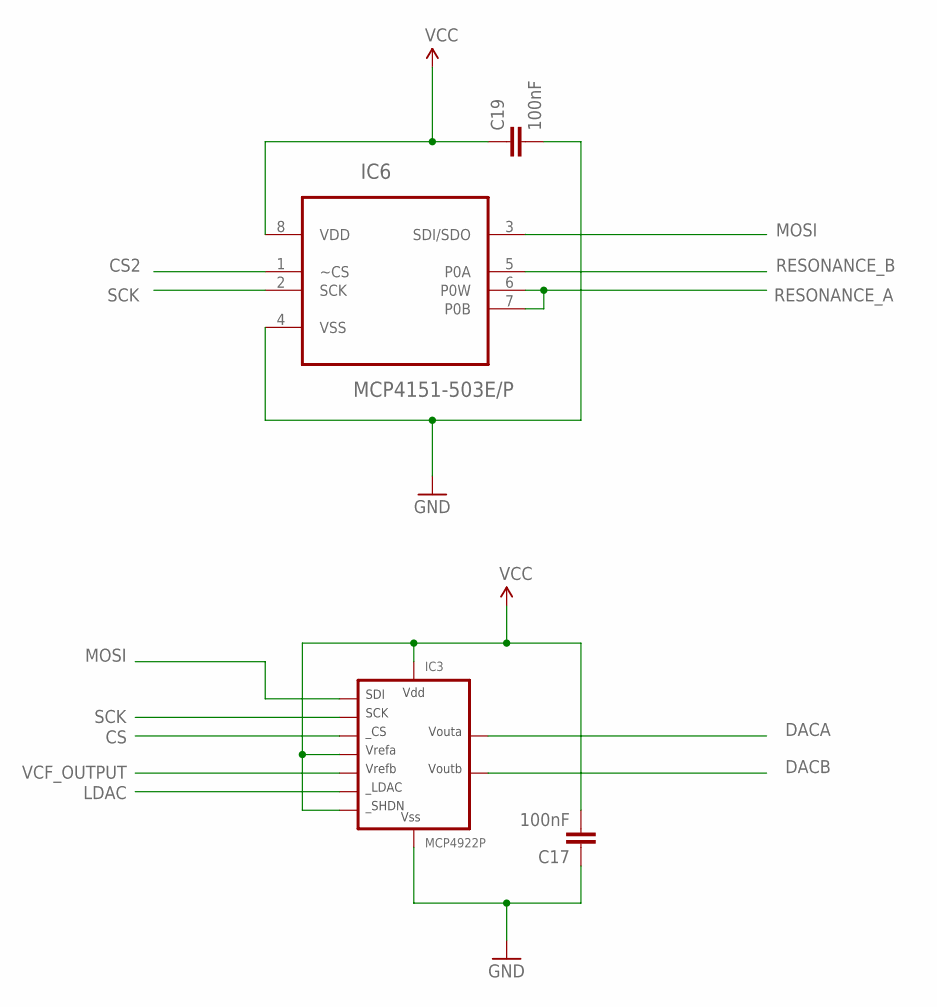
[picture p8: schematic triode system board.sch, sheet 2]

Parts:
C17, C19: 100nF; 0603-CAP
IC3: MCP4922P; DIL14
IC6: MCP4151-503E/P; DIP254P762X533-8

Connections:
CS: IC3.3 (CS); also elsewhere on the board
CS2: IC6.1 (~CS); also elsewhere on the board
DACA: IC3.14 (VOUTA); also elsewhere on the board
DACB: IC3.10 (VOUTB); also elsewhere on the board
GND: C17.1, C19.2, IC3.12 (VSS), IC6.4 (VSS); also elsewhere on the board
LDAC: IC3.8 (LDAC); also elsewhere on the board
MOSI: IC3.5 (SDI), IC6.3 (SDI/SDO); also elsewhere on the board
RESONANCE_A: IC6.6 (P0W), IC6.7 (P0B); also elsewhere on the board
RESONANCE_B: IC6.5 (P0A); also elsewhere on the board
SCK: IC3.4 (SCK), IC6.2 (SCK); also elsewhere on the board
VCC: C17.2, C19.1, IC3.1 (VDD), IC3.9 (SHDN), IC3.13 (VREFA), IC6.8 (VDD); also elsewhere on the board
VCF_OUTPUT: IC3.11 (VREFB); also elsewhere on the board

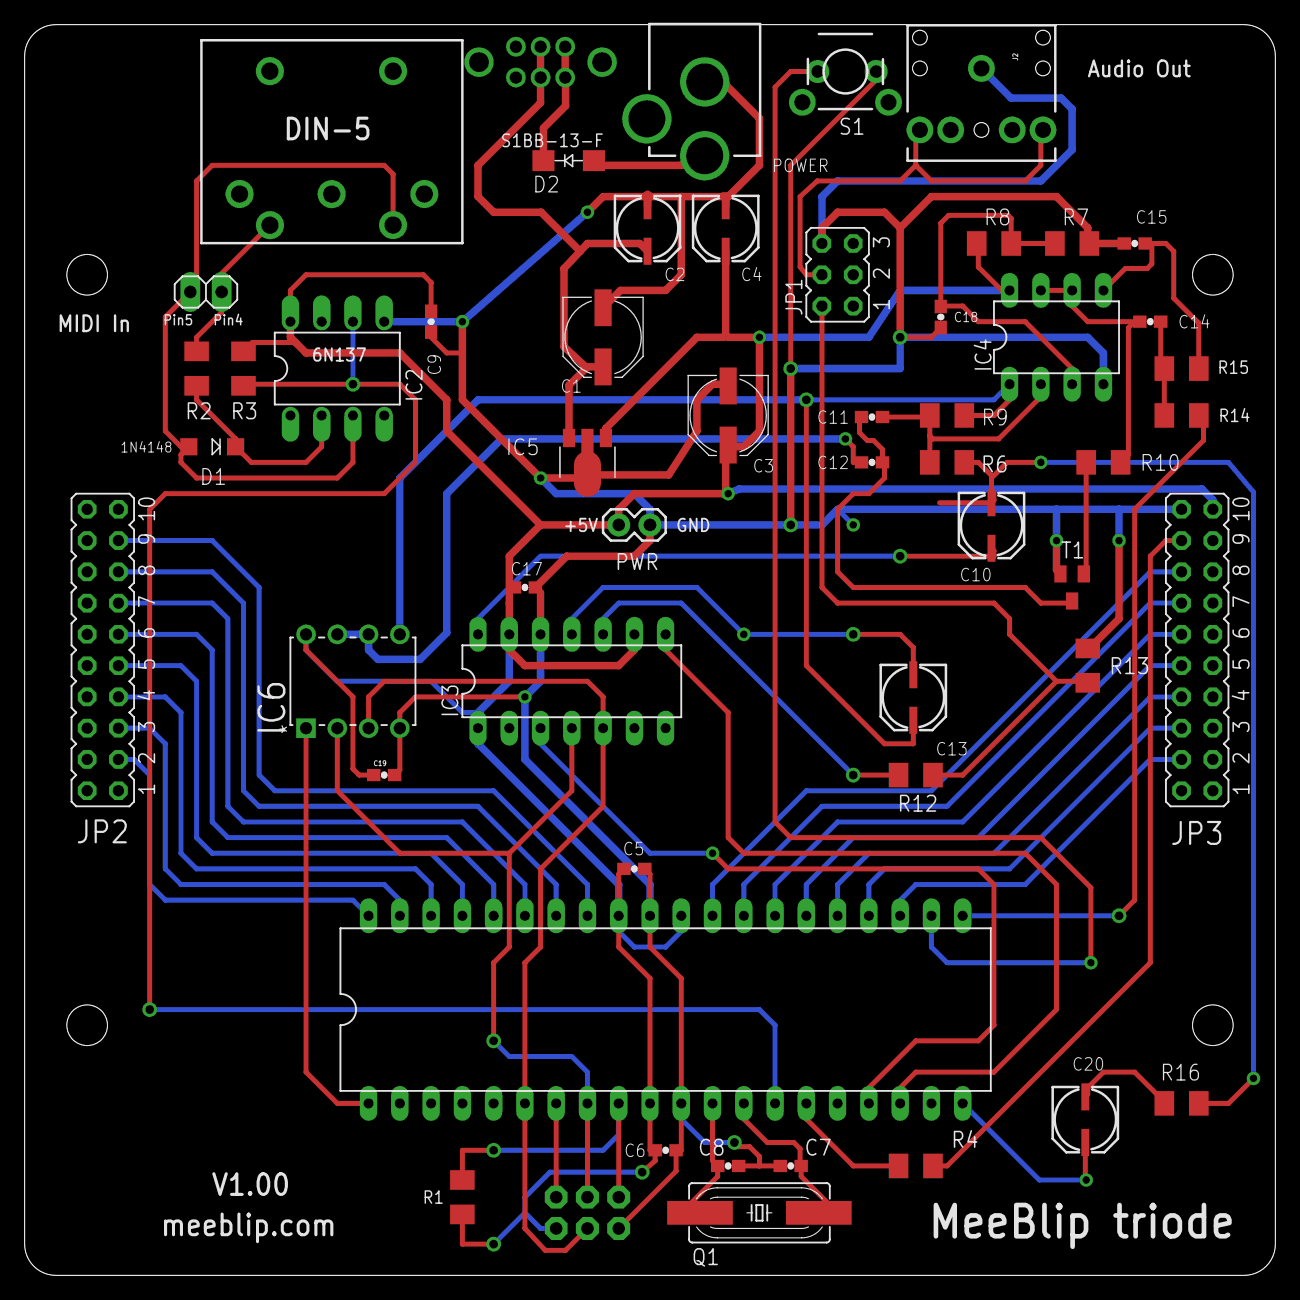
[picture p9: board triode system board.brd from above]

Board: 2 copper layers, 101.6 x 101.6 mm, 58 parts (1 on the bottom side), 54 nets.

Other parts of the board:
H1, H2, H3, H4: STAND-OFF

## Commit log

2016-10-19 MeeBlip triode
    MeeBlip triode monophonic MIDI synthesizer
    [triode control board.brd, triode control board.sch, triode system board.brd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]
2016-10-26 triode V1.01
    Minor bug fixes and additions
    [triode.asm]
2016-11-13 Version 1.10
    Bug fixes, improvements
    [triode.asm]
2017-03-08 MIDI update
    Patched MIDI interrupt to work with MIDI Clock.
